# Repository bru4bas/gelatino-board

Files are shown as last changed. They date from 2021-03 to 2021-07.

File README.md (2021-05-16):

# gelatino-board
Arduino meets iCE40 FPGA

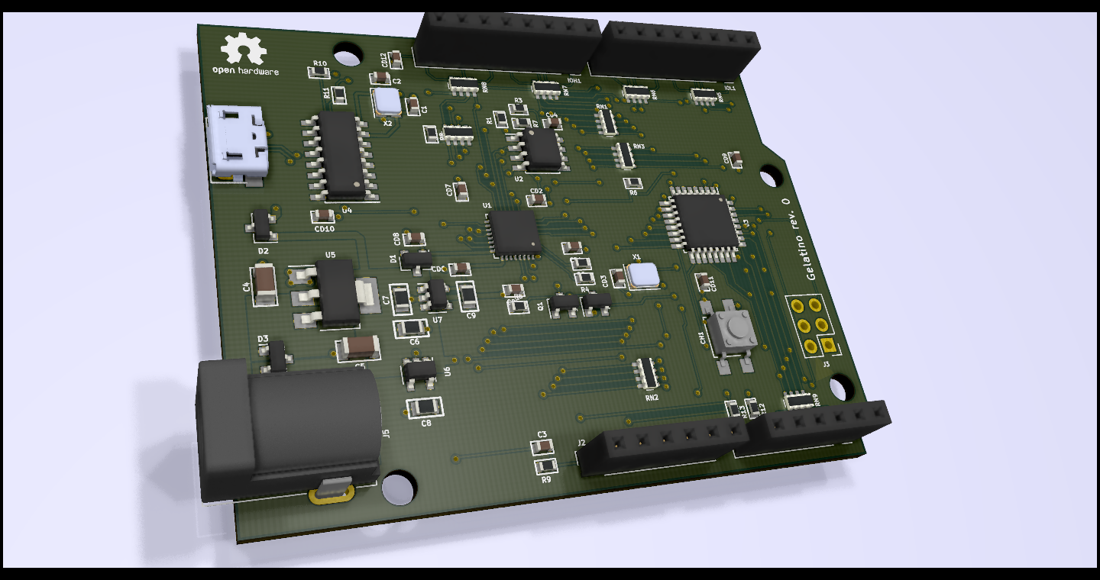
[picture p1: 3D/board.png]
Board picture 3d Board 3D model


This project is meant to be a low-cost FPGA development board, targeting education (Verilog and FPGA) and hobbist users and employing exclusively open-source software and hardware.

It is based on the iCE40LP384 FPGA from Lattice Semiconductor, embedded together with a ATMega328 Arduino-like hardware. Both MCU and FPGA can work together in the Arduino compatible board, and shall be programmed using the traditional Arduino IDE, with extensions. FPGA programming is carried out by the ATMega MCU itself, with an extension of the Arduino standard bootloader -- transfering data to the Flash serial memory, that is shared by both devices.

All hardware is being developed with KiCAD and is published as open-source (GPL).

The main ideas of the project are:
  * Low-lost -- use the cheapest possible components
  * Relative simplicity of production, even hand-made -- avoid smaller IC packages (like BGA)
  * Open-source software only: Arduino environment (avr-gcc, avrdude, ...) and icestorm framework (yosys, icestorm, nextpnr, ...)

Up to now, the project roadmap is
- [x] Preliminary electronic design
- [x] Preliminary bill-of-materials (components from lcsc.com)
- [x] Initial PCB design
- [ ] Conclusion of electronic design and final BOM
- [ ] Building and testing a prototype
- [ ] Changing the Arduino Bootloader for providing FPGA Flash memory programming
- [ ] Coding a extension for the Arduino IDE to deal with Verilog files
  
  Everyone interested in joining this project is welcome!
  
  Many thanks to FPGA WARS, for most of electronic design was inspired from -- mainly the board Alhambra II -- and the amazing projects Yosys and IceStorm.

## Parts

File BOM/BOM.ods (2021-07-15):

Item | Qty | Reference(s) | Value | Footprint | Manufacturer | Part | LCSC# | Price | Total
1 | 2 | C1, C2 | 33pF | SMD 0603 |  | FN18N330J500PSG | C363551 | 0.0034 | 0.0068
2 | 13 | C3, CD1, CD2, CD3, CD4, CD5, CD6, CD7, CD8, CD9, CD10, CD11, CD12 | 100nF | SMD 0603 |  | TCC0603X7R104K500CTC282519 |  | 0.0034 | 0.0442
3 | 2 | C4, C5 | 10uF | SMD 1206 |  | CL31A106KOHNNNE | C1849 | 0.0354 | 0.0708
4 | 4 | C6, C7, C8, C9 | 1uF | SMD 0805 |  | CL21F105ZOFNNNE | C16834 | 0.0104 | 0.0416
5 | 1 | CH1 | RESET |  | Booleme | C174049 | C174049 | 0.0149 | 0.0149
6 | 3 | D1, D2, D3 | BAT54 | SOT-23 | Guangdong | BAT54A | C181198 | 0.0125 | 0.0375
7 | 2 | IOH1, IOL1 | Conn_01x08 | Socket PTH
8 | 2 | J1,J2 | AD | Socket PTH
9 | 1 | J3 | ICSP | Header PTH
10 | 1 | J4 | USB |  | XKB | U254-051T-4BH83-F1S | C397452 | 0.0253 | 0.0253
11 | 1 | J5 | POWER |  |  | DC-005-20A | C136744 | 0.0949 | 0.0949
12 | 2 | Q1, Q2 | 2N7002 | SOT-23 | Guangdong | 2N7002 | C181082 | 0.0143 | 0.0286
13 | 7 | R1, R3, R5, R6, R7, R8, R9 | 10k | SMD 0603 |  | RC0603JR-0710KL | C99198 | 0.0012 | 0.0084
14 | 2 | R2, R4 | 100 | SMD 0603 |  | 0603WAJ0101T5E | C25201 | 0.0012 | 0.0024
15 | 4 | R10, R11, R12, R13 | 1k | SMD 0603 |  | WR06X102JTL | C384295 | 0.0012 | 0.0048
16 | 4 | RN1, RN2, RN3, RN4 | 100 | SMD 0603 x 4 | Walsin | WA06X101JTL | C384483 | 0.0056 | 0.0224
17 | 5 | RN5, RN6, RN7, RN8, RN9 | 1k | SMD 0603 x 4 | FH | RC-ML08W102JT | C160614 | 0.0087 | 0.0435
18 | 1 | U1 | iCE40LP384 | QFN-32 |  |  |  |  | 0
19 | 1 | U2 | AT25xxx | SO-8 | XTX | XT25F02ESOIGU | C596312 | 0.2487 | 0.2487
20 | 1 | U3 | ATMega328 | TQFP-32 | Atmel | ATMEGA328PB-AU | C132230 | 3.9694 | 3.9694
21 | 1 | U4 | CH340G | SO-16 | WCH | CH340G/B/C | C84681 | 0.5284 | 0.5284
22 | 1 | U5 | AMS1117-5.0 | SOT-223 |  | AMS1117-5.0 | C347223 | 0.0868 | 0.0868
23 | 1 | U6 | RT9013-33 | SOT-23-5 | Microne | ME6211C33M5G-N | C82942 | 0.0796 | 0.0796
24 | 1 | U7 | RT9013-12 | SOT-23-5 | Microne | ME6211C12M5G-N | C236672 | 0.076 | 0.076
25 | 1 | X1 | 16MHz | SMD 3225 4 pin | SCTF | S3D16.000000B20F30T | C387369 | 0.5915 | 0.5915
26 | 1 | X2 | 12 MHz | SMD 3225 4 pin | HD | 7B012000I01 | C654948 | 0.1123 | 0.1123
 |  |  |  |  |  |  | Total |  | 6.1388

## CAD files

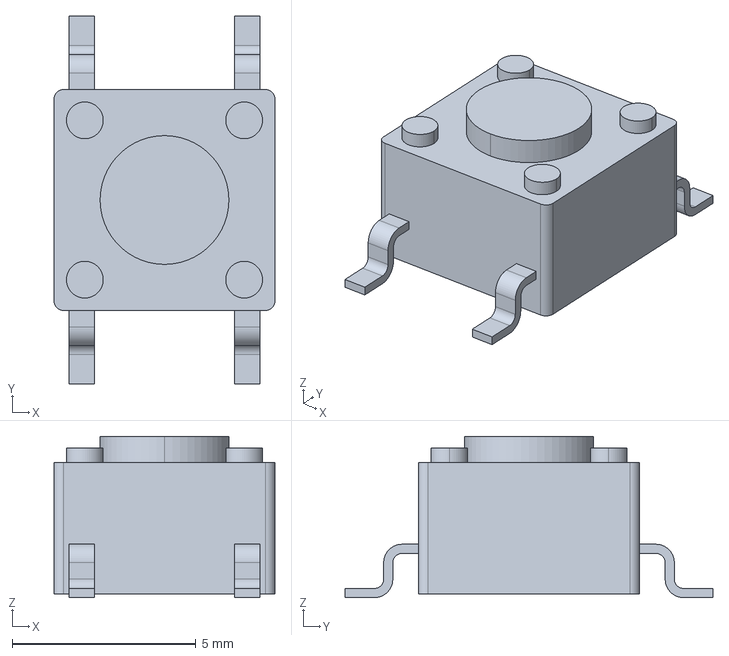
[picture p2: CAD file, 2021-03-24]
3D/2-1437565-8.stp
6.00 x 10.0 x 4.38 mm

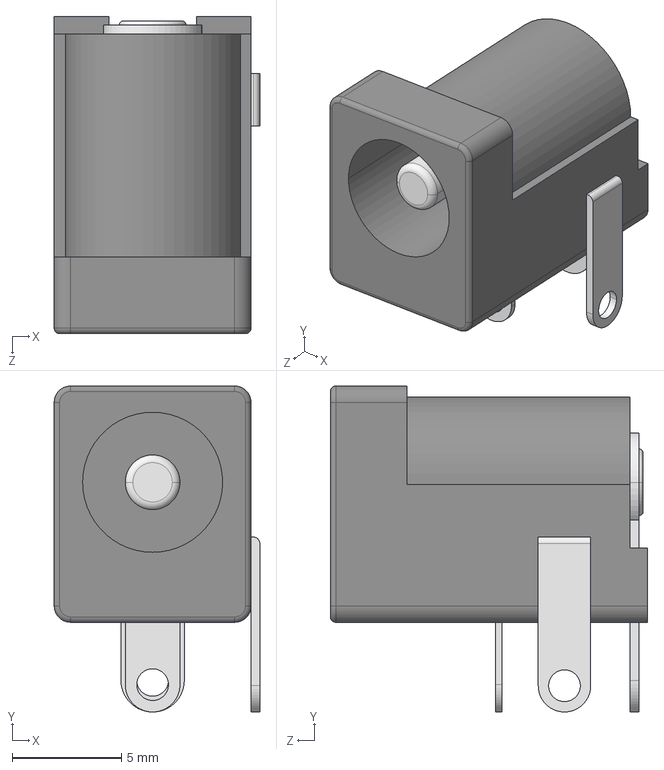
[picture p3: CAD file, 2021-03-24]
3D/KLDX-0202-B_rD3.STEP
9.40 x 14.9 x 14.5 mm

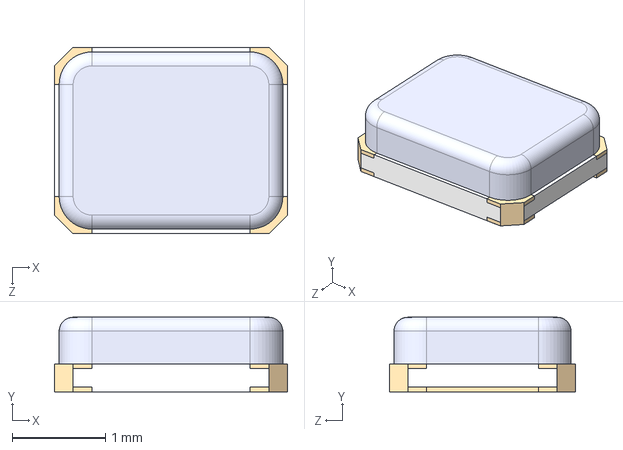
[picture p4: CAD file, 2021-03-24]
3D/XRCHA16M000F0A01R0--3DModel-STEP-56544.STEP
2.50 x 0.8 x 2.00 mm

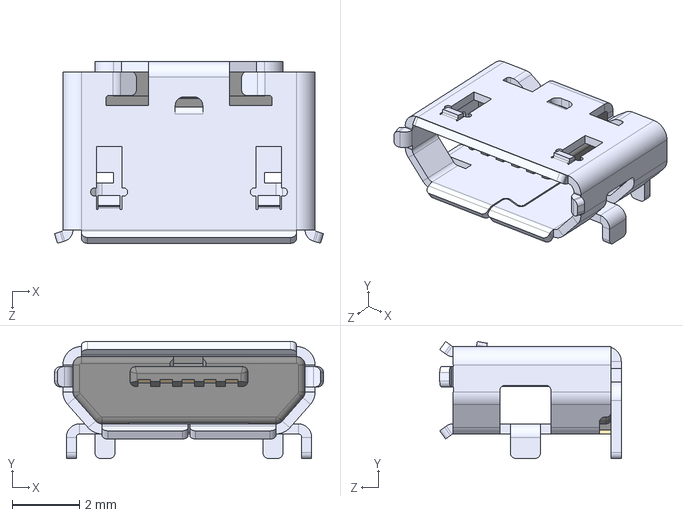
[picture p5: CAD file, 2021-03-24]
3D/1050170001--3DModel-STEP-56544.STEP
8.00 x 3.48 x 5.40 mm

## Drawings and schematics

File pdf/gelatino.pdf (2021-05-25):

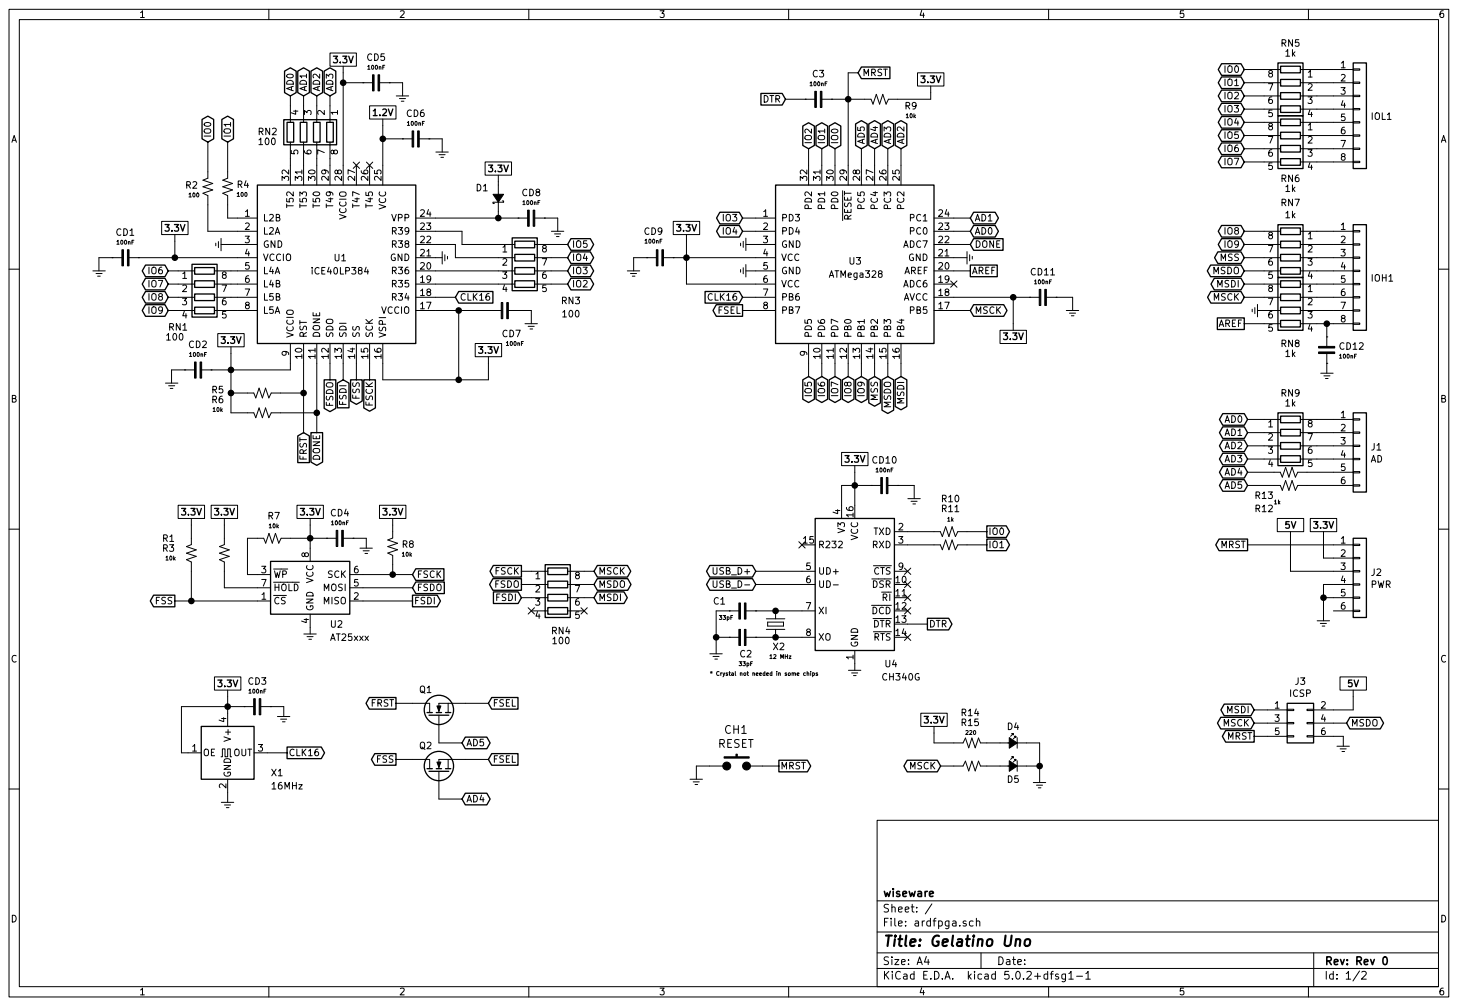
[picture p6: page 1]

* Crystal not needed in some chips

File: ardfpga.sch Sheet: / wiseware

Id: 1/2 Title: Gelatino Uno

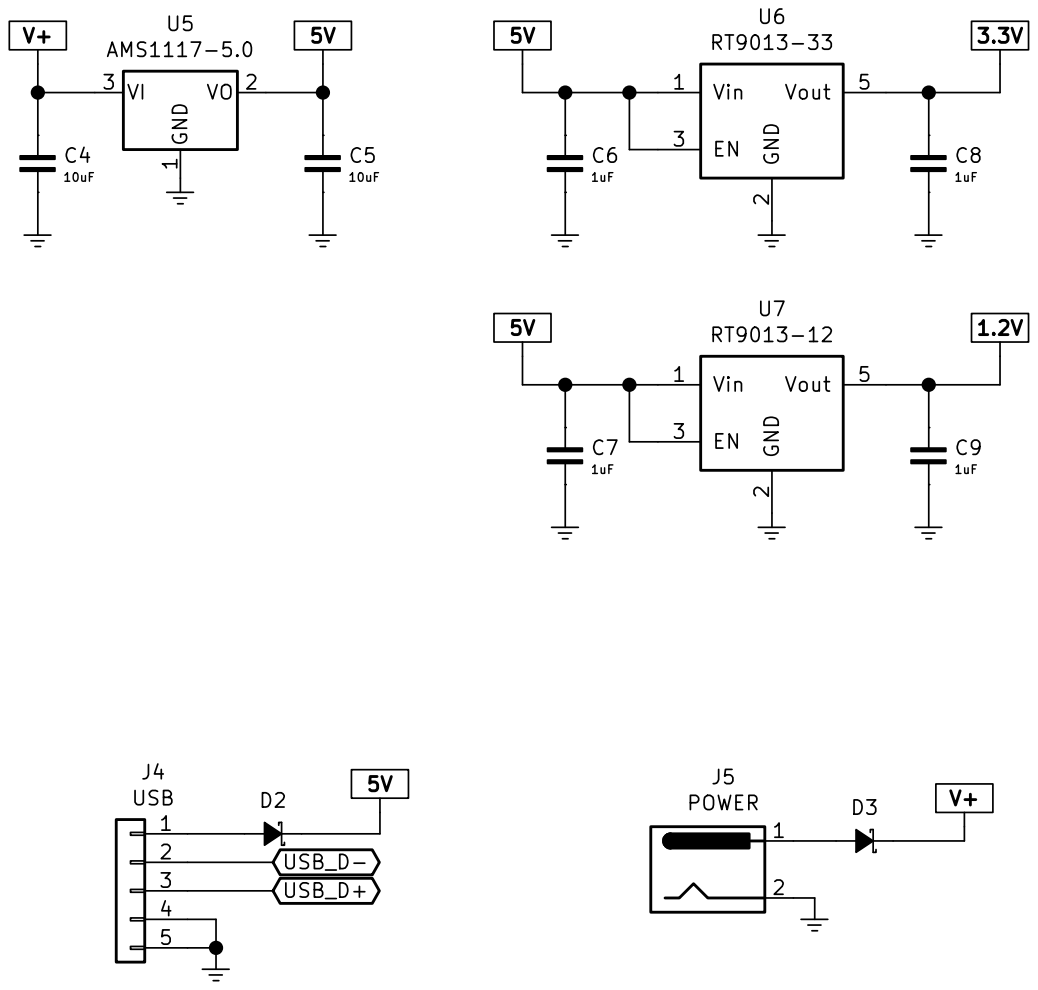
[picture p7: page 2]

File: power.sch Sheet: /Power/
Id: 2/2 Title: Alimentação

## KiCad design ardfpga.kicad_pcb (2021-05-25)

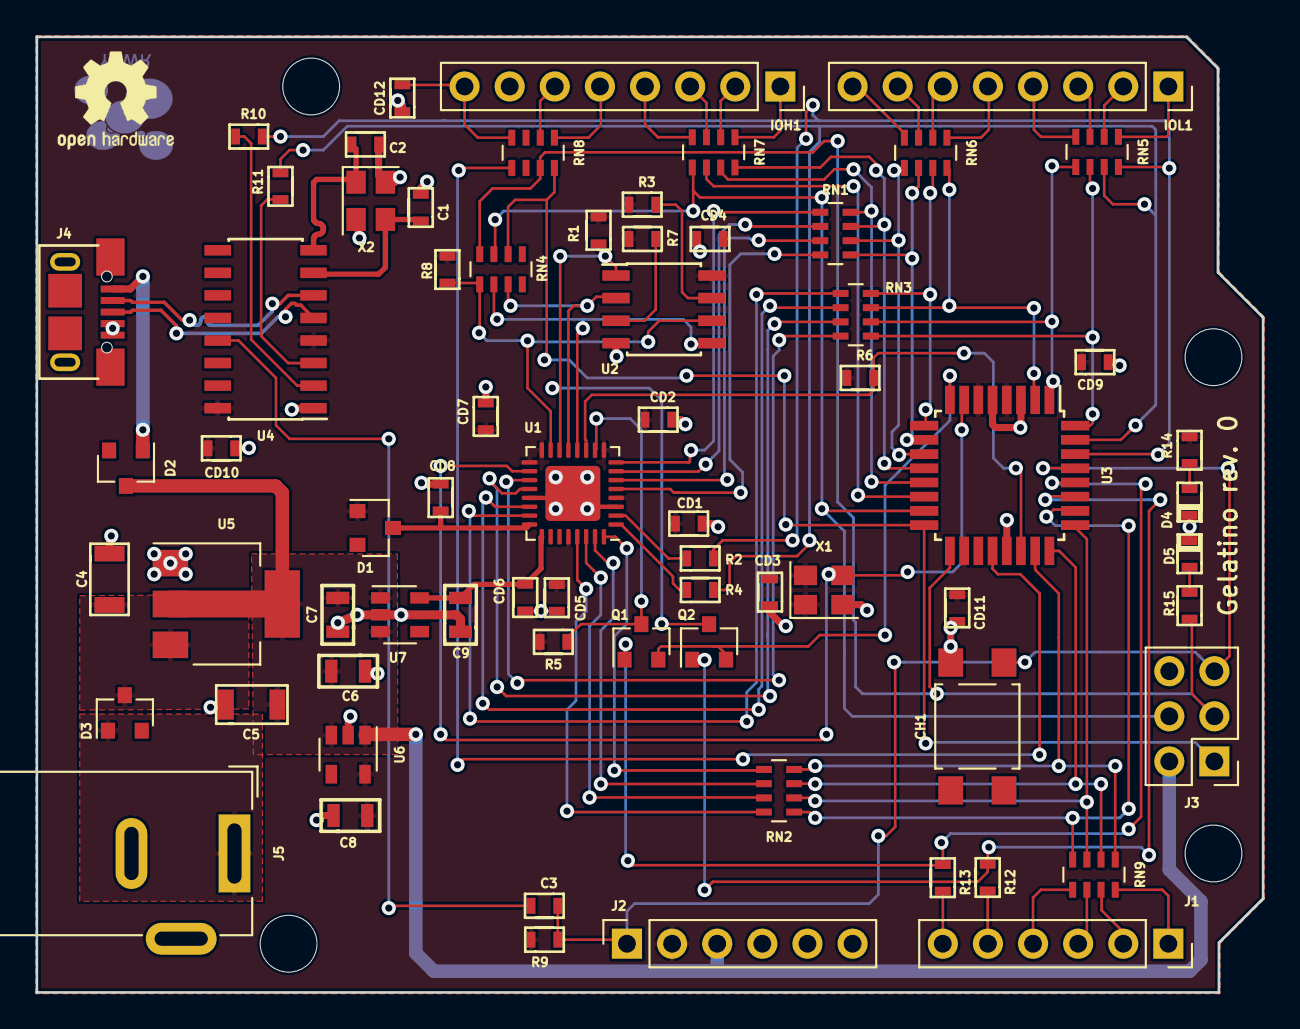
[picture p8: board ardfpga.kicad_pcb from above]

Board: 2 copper layers, 69.0 x 53.8 mm, 69 parts (0 on the bottom side), 84 nets.

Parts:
C1, C2: 33pF; 0603_CAP
C3: 100nF; 0603_CAP
C4, C5: 10uF; 1206_SMD
C6, C7, C8, C9: 1uF; 0805_SMD
CD1, CD2, CD3, CD4, CD5, CD6, CD7, CD8, CD9, CD10, CD11, CD12: 100nF; 0603_CAP
CH1: RESET; SW_SPST_TL3305A
D1, D2, D3: D_Schottky_Small_ALT; SOT-23
D4, D5: LED_Small_ALT; 0603_LED
IOH1: Conn_01x08; PinSocket_1x08_P2.54mm_Vertical
IOL1: Conn_01x08; PinSocket_1x08_P2.54mm_Vertical
J1: AD; PinSocket_1x06_P2.54mm_Vertical
J2: PWR; PinSocket_1x06_P2.54mm_Vertical
J3: ICSP; PinHeader_2x03_P2.54mm_Vertical
J4: USB; USB-Micro-LCSC
J5: POWER; BarrelJack_Wuerth_6941xx301002
Q1, Q2: NMOS; SOT-23
R1, R3, R5, R6, R7, R8, R9: 10k; 0603_RES
R2, R4: 100; 0603_RES
R10, R11, R12, R13: 1k; 0603_RES
R14, R15: 220; 0603_RES
RN1, RN2, RN3, RN4: 100; R_Array_Concave_4x0603
RN5, RN6, RN7, RN8, RN9: 1k; R_Array_Concave_4x0603
U1: iCE40LP384; QFN-32-1EP_5x5mm_P0.5mm_EP3.1x3.1mm
U2: AT25xxx; SOIC-8_3.9x4.9mm_P1.27mm
U3: ATMega328; TQFP-32_7x7mm_P0.8mm
U4: CH340G; SOIC-16_3.9x9.9mm_P1.27mm
U5: AMS1117-5.0; SOT-223-3_TabPin2
U6: RT9013-33; SOT-23-5
U7: RT9013-12; SOT-23-5
X1: 16MHz; Oscillator_SMD_Abracon_ASE-4Pin_3.2x2.5mm
X2: 12 MHz; Oscillator_SMD_Abracon_ASE-4Pin_3.2x2.5mm

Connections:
+1.2V: C9.1, CD6.1, U1.25, U7.5
+3.3V: C8.1, CD1.1, CD2.1, CD3.1, CD4.1, CD5.1, CD7.1, CD9.2, CD10.1, CD11.1, D1.1, J2.2, R1.1, R3.1, R5.1, R6.1, R7.2, R8.1, R9.2, R14.2, U1.4, U1.9, U1.16, U1.17, U1.28, U2.8, U3.4, U3.6, U3.18, U4.4, U4.16, U6.5, X1.1, X1.4
+5V: C5.1, C6.1, C7.1, D2.3, J2.3, J3.2, U5.2, U6.1, U6.3, U7.1, U7.3
AD0: RN2.4, RN9.1, U3.23
AD1: RN2.3, RN9.2, U3.24
AD2: RN2.2, RN9.3, U3.25
AD3: RN2.1, RN9.4, U3.26
AD4: Q2.G, R12.1, U3.27
AD5: Q1.G, R13.1, U3.28
AREF: RN8.5, U3.20
CLK16: U1.18, U3.7, X1.3
DONE: R6.2, U1.11, U3.22
DTR: C3.1, U4.13
FRST: Q1.D, R5.2, U1.10
FSCK: R8.2, RN4.1, U1.15, U2.6
FSDI: RN4.3, U1.13, U2.2
FSDO: RN4.2, U1.12, U2.5
FSEL: Q1.S, Q2.S, U3.8
FSS: Q2.D, R1.2, U1.14, U2.1
GND: C1.1, C2.1, C4.2, C5.2, C6.2, C7.2, C8.2, C9.2, CD1.2, CD2.2, CD3.2, CD4.2, CD5.2, CD6.2, CD7.2, CD8.2, CD9.1, CD10.2, CD11.2, CD12.2, CH1.1, D4.1, D5.1, IOH1.7, J2.4, J2.5, J3.6, J4.4, J4.5, J5.2, U1.3, U1.21, U1.33, U2.4, U3.3, U3.5, U3.21, U4.1, U5.1, U6.2, U7.2, X1.2, X2.0
IO0: R2.1, R10.2, RN5.8, U3.30
IO1: R4.1, R11.2, RN5.7, U3.31
IO2: RN3.5, RN5.6, U3.32
IO3: RN3.6, RN5.5, U3.1
IO4: RN3.7, RN6.8, U3.2
IO5: RN3.8, RN6.7, U3.9
IO6: RN1.1, RN6.6, U3.10
IO7: RN1.2, RN6.5, U3.11
IO8: RN1.3, RN7.8, U3.12
IO9: RN1.4, RN7.7, U3.13
MRST: C3.2, CH1.2, J2.1, J3.5, R9.1, U3.29
MSCK: J3.3, R15.2, RN4.8, RN8.7, U3.17
MSDI: J3.1, RN4.6, RN8.8, U3.16
MSDO: J3.4, RN4.7, RN7.5, U3.15
MSS: RN7.6, U3.14
unnamed: C1.2, U4.7, X2.2
unnamed: C2.2, U4.8, X2.1
unnamed: CD8.1, D1.3, U1.24
unnamed: CD12.1, IOH1.8, RN8.4
unnamed: D2.1, J4.1
unnamed: D3.1, J5.1
unnamed: D4.2, R14.1
unnamed: D5.2, R15.1
unnamed: IOH1.1, RN7.1
unnamed: IOH1.2, RN7.2
unnamed: IOH1.3, RN7.3
unnamed: IOH1.4, RN7.4
unnamed: IOH1.5, RN8.1
unnamed: IOH1.6, RN8.2
unnamed: IOL1.1, RN5.1
unnamed: IOL1.2, RN5.2
unnamed: IOL1.3, RN5.3
unnamed: IOL1.4, RN5.4
unnamed: IOL1.5, RN6.1
unnamed: IOL1.6, RN6.2
unnamed: IOL1.7, RN6.3
unnamed: IOL1.8, RN6.4
unnamed: J1.1, RN9.8
unnamed: J1.2, RN9.7
unnamed: J1.3, RN9.6
unnamed: J1.4, RN9.5
unnamed: J1.5, R12.2
unnamed: J1.6, R13.2
unnamed: R2.2, U1.2
unnamed: R3.2, U2.7
unnamed: R4.2, U1.1
unnamed: R7.1, U2.3
unnamed: R10.1, U4.2
unnamed: R11.1, U4.3
unnamed: RN1.5, U1.8
unnamed: RN1.6, U1.7
unnamed: RN1.7, U1.6
unnamed: RN1.8, U1.5
unnamed: RN2.5, U1.32
unnamed: RN2.6, U1.31
unnamed: RN2.7, U1.30
unnamed: RN2.8, U1.29
unnamed: RN3.1, U1.23
unnamed: RN3.2, U1.22
unnamed: RN3.3, U1.20
unnamed: RN3.4, U1.19
USB_D+: J4.3, U4.5
USB_D-: J4.2, U4.6
V+: C4.1, D3.3, U5.3

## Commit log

2021-03-24 Kicad files for Gelatino Board first commit.
    [BOM.ods, ardfpga.kicad_pcb, ardfpga.sch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]
2021-03-24 Added 3d image of the board for github README file.
    [1050170001--3DModel-STEP-56544.STEP, 2-1437565-8.stp, KLDX-0202-B_rD3.STEP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]
2021-05-16 Board routed, circuit changed to ease PCB routing. Minor adjustments. Ready to re-check PCB.
    [ardfpga.kicad_pcb, ardfpga.sch]
2021-05-24 Board revision, leds added. Better routing.
    [ardfpga.kicad_pcb, ardfpga.sch]
2021-05-25 Bugs in the board corrected. Better routing. First BOM version.
    [BOM.ods, ardfpga.kicad_pcb, ardfpga.sch]
2021-07-14 Add price column title to BOM
    [BOM.ods]
